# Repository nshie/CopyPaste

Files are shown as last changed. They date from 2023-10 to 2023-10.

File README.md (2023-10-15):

# CopyPaste
Split 40% Bluetooth Keyboard

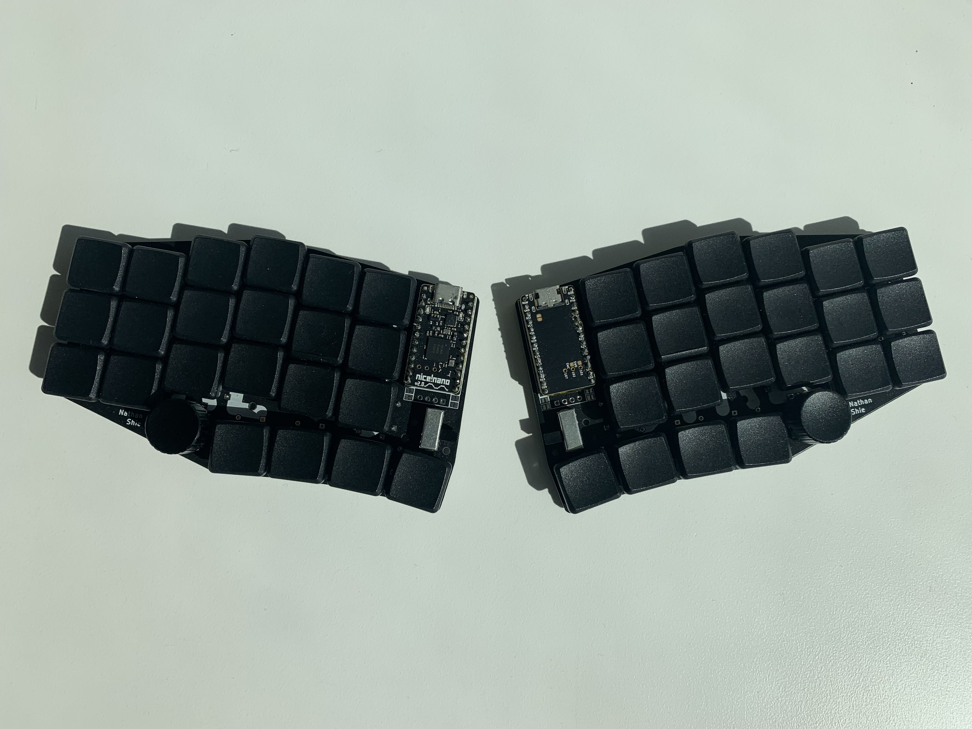
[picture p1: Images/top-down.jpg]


### Motivation
I wanted a portable, light keyboard to bring to class, with stenography (chording) and bluetooth capabilities.

### Design
- symmetrical design so both sides of the PCB can be soldered to get the left and right halves
  - JLCPCB minimum order quantity is 5, so might as well use 2/5 instead of buying 2 different PCBs and using 2/10
- choc low profile switches for portability
- nice!nano for easy hand soldering (as opposed to soldering my own MCUs)
- thumb switches as close together as possible for chording
- rotary encoder for alt-tab on the left, volume on the right
- ports for oled display (not recommended because of battery drain)
  - mounting holes for acrylic screen protector
- pads for ws2812b leds (not recommended because of battery drain)

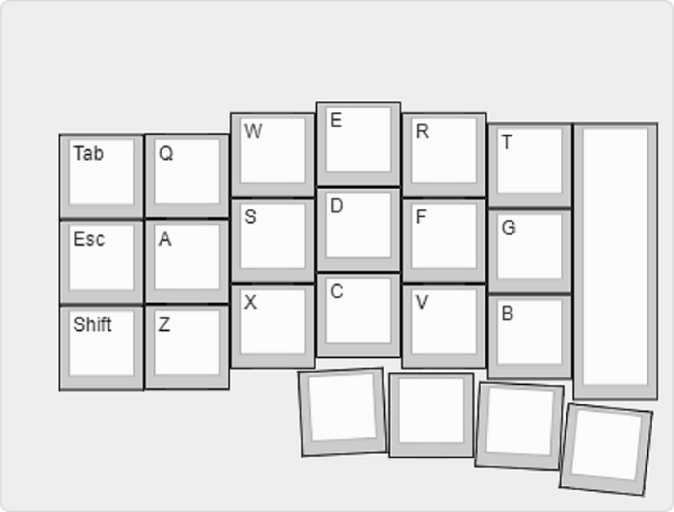
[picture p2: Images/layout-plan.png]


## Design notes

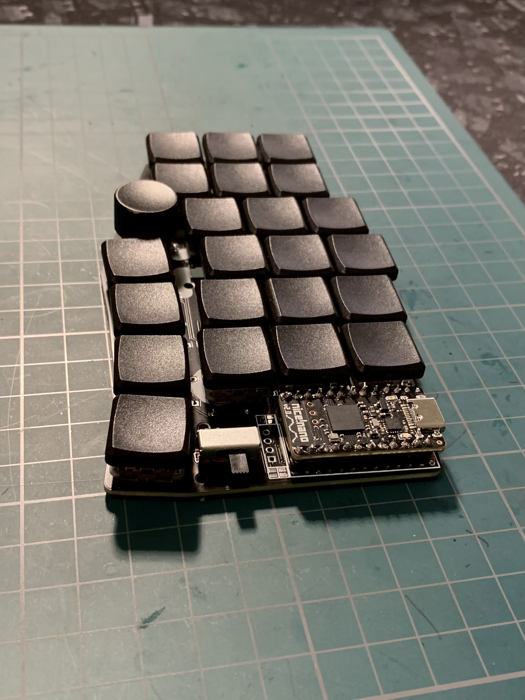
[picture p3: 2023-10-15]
Images/side.jpg

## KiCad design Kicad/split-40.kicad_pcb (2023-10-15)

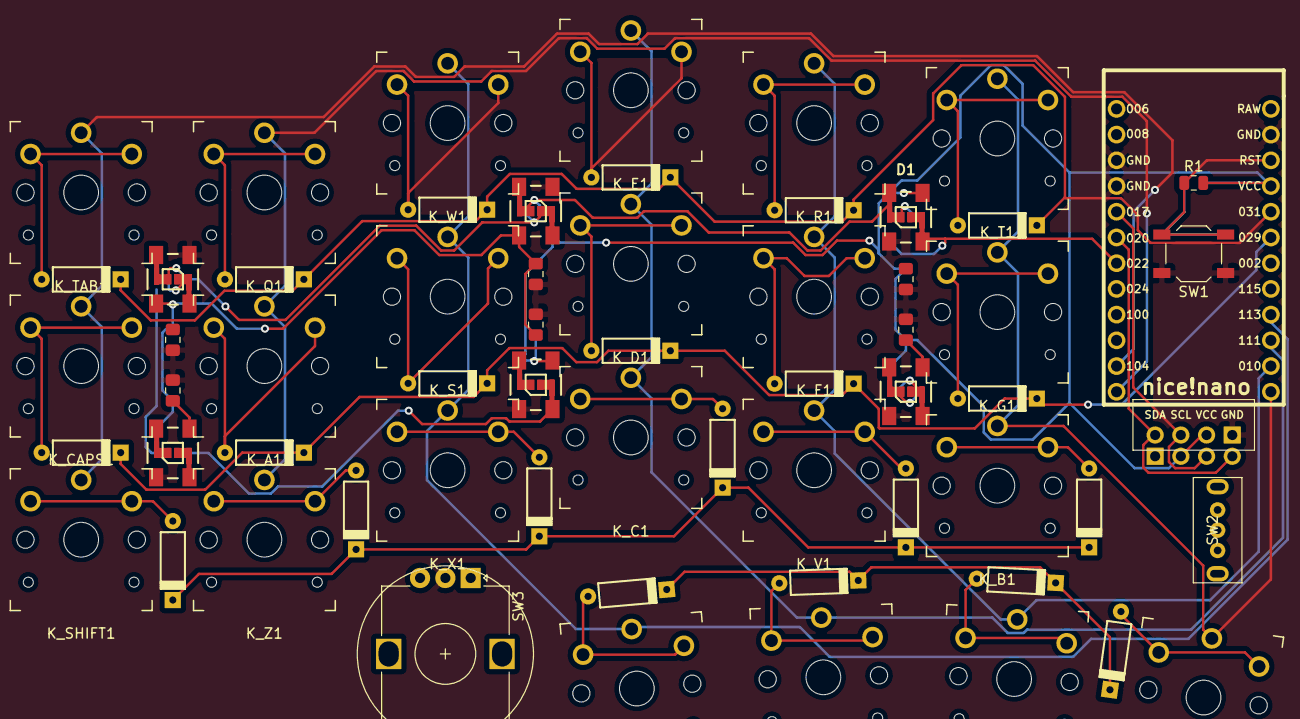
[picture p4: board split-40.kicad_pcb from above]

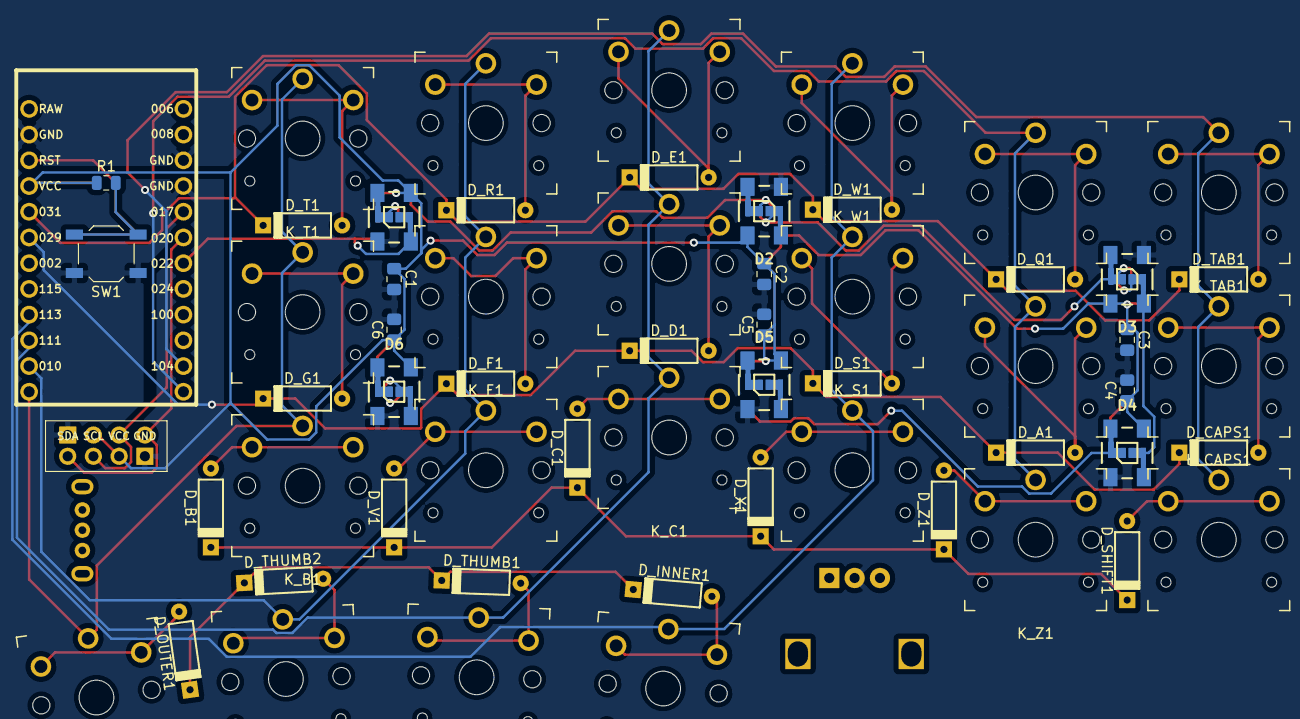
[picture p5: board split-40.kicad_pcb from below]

Board: 2 copper layers, 63 parts (36 on the bottom side), 46 nets.

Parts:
C1, C2, C3, C4, C5, C6: 0.1uF; C_0805_Reversible
D1, D2, D3, D4, D5, D6: WS2812B; WS2812B_data-bridgeable_Reversible
D_A1: D; D_axial_reversible
D_B1: D; D_axial_reversible
D_C1: D; D_axial_reversible
D_CAPS1: D; D_axial_reversible
D_D1: D; D_axial_reversible
D_E1: D; D_axial_reversible
D_F1: D; D_axial_reversible
D_G1: D; D_axial_reversible
D_INNER1: D; D_axial_reversible
D_OUTER1: D; D_axial_reversible
D_Q1: D; D_axial_reversible
D_R1: D; D_axial_reversible
D_S1: D; D_axial_reversible
D_SHIFT1: D; D_axial_reversible
D_T1: D; D_axial_reversible
D_TAB1: D; D_axial_reversible
D_THUMB1, D_THUMB2: D; D_axial_reversible
D_V1: D; D_axial_reversible
D_W1: D; D_axial_reversible
D_X1: D; D_axial_reversible
D_Z1: D; D_axial_reversible
K_A1: KEYSW; SW_PG1350_reversible_outlined
K_B1: KEYSW; SW_PG1350_reversible_outlined
K_C1: KEYSW; SW_PG1350_reversible_outlined
K_CAPS1: KEYSW; SW_PG1350_reversible_outlined
K_D1: KEYSW; SW_PG1350_reversible_outlined
K_E1: KEYSW; SW_PG1350_reversible_outlined
K_F1: KEYSW; SW_PG1350_reversible_outlined
K_G1: KEYSW; SW_PG1350_reversible_outlined
K_INNER1: KEYSW; SW_PG1350_reversible_outlined
K_OUTER1: KEYSW; SW_PG1350_reversible_outlined
K_Q1: KEYSW; SW_PG1350_reversible_outlined
K_R1: KEYSW; SW_PG1350_reversible_outlined
K_S1: KEYSW; SW_PG1350_reversible_outlined
K_SHIFT1: KEYSW; SW_PG1350_reversible_outlined
K_T1: KEYSW; SW_PG1350_reversible_outlined
K_TAB1: KEYSW; SW_PG1350_reversible_outlined
K_THUMB1, K_THUMB2: KEYSW; SW_PG1350_reversible_outlined
K_V1: KEYSW; SW_PG1350_reversible_outlined
K_W1: KEYSW; SW_PG1350_reversible_outlined
K_X1: KEYSW; SW_PG1350_reversible_outlined
K_Z1: KEYSW; SW_PG1350_reversible_outlined
L1, L1#2: SSD1306_OLED_Display; SSD1306-0.91-OLED-4pin-128x32
R1: 10k; R_0805_2012Metric
SW1: SW_Push; SW_SPST_TL3342
SW2: SW_SPDT; SK12D07VG3-Mini-SPDT-Slide-Switch-Right-Angle
SW3: Rotary_Encoder; RotaryEncoder_Alps_EC12E_Vertical_H20mm
U1: nice_nano

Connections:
GND: C1.2, C2.2, C3.2, C4.2, C5.2, C6.2, D1.3, D2.3, D3.3, D4.3, D5.3, D6.3, L1.1, L1#2.1, SW1.1, SW3.C, U1.3, U1.4, U1.23
unnamed: D1.2, D2.4
unnamed: D2.2, D3.4
unnamed: D3.2, D4.4
unnamed: D4.2, D5.4
unnamed: D5.2, D6.4
unnamed: D_A1.2, K_A1.2
unnamed: D_B1.2, K_B1.2
unnamed: D_C1.2, K_C1.2
unnamed: D_CAPS1.2, K_CAPS1.2
unnamed: D_D1.2, K_D1.2
unnamed: D_E1.2, K_E1.2
unnamed: D_F1.2, K_F1.2
unnamed: D_G1.2, K_G1.2
unnamed: D_INNER1.2, K_INNER1.2
unnamed: D_OUTER1.2, K_OUTER1.2
unnamed: D_Q1.2, K_Q1.2
unnamed: D_R1.2, K_R1.2
unnamed: D_S1.2, K_S1.2
unnamed: D_SHIFT1.2, K_SHIFT1.2
unnamed: D_T1.2, K_T1.2
unnamed: D_TAB1.2, K_TAB1.2
unnamed: D_THUMB1.2, K_THUMB1.2
unnamed: D_THUMB2.2, K_THUMB2.2
unnamed: D_V1.2, K_V1.2
unnamed: D_W1.2, K_W1.2
unnamed: D_X1.2, K_X1.2
unnamed: D_Z1.2, K_Z1.2
unnamed: R1.2, SW1.2, U1.22
unnamed: SW2.1, U1.24
SCL: L1.3, L1#2.3, U1.5
SDA: L1.4, L1#2.4, U1.6
VCC: C1.1, C2.1, C3.1, C4.1, C5.1, C6.1, D1.1, D2.1, D3.1, D4.1, D5.1, D6.1, L1.2, L1#2.2, R1.1, U1.21
col0: K_CAPS1.1, K_SHIFT1.1, K_TAB1.1, U1.11
col1: K_A1.1, K_Q1.1, K_Z1.1, U1.12
col2: K_INNER1.1, K_S1.1, K_W1.1, K_X1.1, U1.16
col3: K_C1.1, K_D1.1, K_E1.1, K_THUMB1.1, U1.15
col4: K_F1.1, K_R1.1, K_THUMB2.1, K_V1.1, U1.14
col5: K_B1.1, K_G1.1, K_OUTER1.1, K_T1.1, U1.13
encA: SW3.A, U1.1
encB: SW3.B, U1.2
led: D1.4, U1.7
row0: D_E1.1, D_Q1.1, D_R1.1, D_T1.1, D_TAB1.1, D_W1.1, U1.20
row1: D_A1.1, D_CAPS1.1, D_D1.1, D_F1.1, D_G1.1, D_S1.1, U1.19
row2: D_B1.1, D_C1.1, D_SHIFT1.1, D_V1.1, D_X1.1, D_Z1.1, U1.18
row3: D_INNER1.1, D_OUTER1.1, D_THUMB1.1, D_THUMB2.1, U1.17
